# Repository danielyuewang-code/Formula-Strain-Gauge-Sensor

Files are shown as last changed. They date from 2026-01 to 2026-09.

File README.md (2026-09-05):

# Formula Strain Gauge Sensor
> PCB designs for measuring axial forces on suspension arms in Formula SAE racing applications

## Overview
This repository contains the Altium Designer PCB projects for strain gauge sensor systems designed to measure axial forces on suspension arms in formula racing vehicles. The project includes two design variants optimized for different size and performance requirements.

## Project Structure
### `/CIU` - Full-Featured MCU Board
The larger variant featuring a complete microcontroller solution for data acquisition and processing.
- **biggie.PrjPcb** - Main Altium project file
- **MCU.SchDoc** - Schematic design with MCU, signal conditioning, and power management

### `/smol` - Compact Sensor Board
The compact variant optimized for space-constrained installations.
- **smol.PrjPcb** - Main Altium project file
- **root.SchDoc** - Schematic design
- **smol.PcbDoc** - PCB layout

### `/docs`
Project documentation and design notes.

## Features
- Strain gauge signal conditioning and amplification
- Microcontroller-based data acquisition
- Axial force measurement capabilities
- Multiple size variants for different installation requirements
- Designed for harsh racing environments

## Hardware Requirements
- Altium Designer (for viewing/editing design files)
- Strain gauge sensors (specifications TBD)
- Power supply requirements (specifications TBD)

## Getting Started
1. Clone this repository
2. Open the desired project (.PrjPcb) in Altium Designer
3. Review the schematic and PCB layout files
4. Generate manufacturing outputs as needed

## Design Variants
- **Biggie** - Full-featured board with integrated MCU for standalone operation
- **Smol** - Amplifier board feeding signals

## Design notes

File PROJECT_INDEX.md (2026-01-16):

# Project Index - Formula Strain Gauge Sensor

## Project Overview
**Project Name:** Formula Strain Gauge Sensor  

---

## Repository Structure

```
Formula-Strain-Gauge-Sensor/
├── README.md                      # Project overview and getting started guide
├── PROJECT_INDEX.md               # This file - detailed project index
├── .gitignore                     # Git ignore rules
│
├── biggie/                        # Full-featured MCU variant
│   ├── biggie.PrjPcb             # Main Altium project file
│   ├── MCU.SchDoc                # Schematic - MCU, signal conditioning, power
│   └── __Previews/               # Altium preview files
│       └── MCU.SchDocPreview
│
├── smol/                          # Compact sensor variant
│   ├── smol.PrjPcb               # Main Altium project file
│   ├── root.SchDoc               # Schematic design
│   ├── smol.PcbDoc               # PCB layout
│   ├── __Previews/               # Altium preview files
│   │   └── root.SchDocPreview
│   └── History/                  # Altium version history
│
└── docs/                          # Documentation
    └── Design_Folder.md          # Design documentation
```

---

## Design Variants

### 1. Biggie (Full-Featured Board)
**Location:** `/biggie`  
**Description:** Complete microcontroller-based data acquisition system

**Key Files:**
- `biggie.PrjPcb` - Altium project container
- `MCU.SchDoc` - Main schematic with MCU and signal conditioning

---

### 2. Smol (Compact Board)
**Location:** `/smol`  
**Description:** Space-optimized sensor board for constrained installations

**Key Files:**
- `smol.PrjPcb` - Altium project container
- `root.SchDoc` - Schematic design
- `smol.PcbDoc` - PCB layout

---

## Quick Reference

### Opening Projects
1. Navigate to desired variant folder (`biggie/` or `smol/`)
2. Open the `.PrjPcb` file in Altium Designer
3. Access schematics and PCB files from the project panel

### Documentation
- Design decisions and specifications: `/docs/Design_Folder.md`
- General project info: `README.md`
- Project navigation: This file (`PROJECT_INDEX.md`)

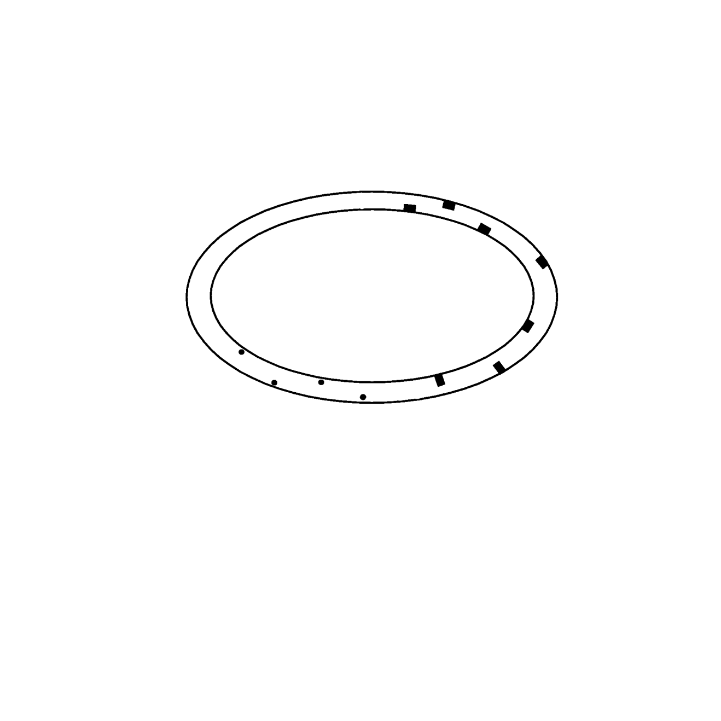
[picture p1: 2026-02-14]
custom_track_2.webp

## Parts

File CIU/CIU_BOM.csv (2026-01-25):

Comment | Description | Designator | Footprint | LibRef | Quantity
1u | CC0603KRX7R7BB105 | C1, C2, C3, C4, C5, C7 | CAPC1608X90N | CC0603KRX7R7BB105 | 6
10u | GRM188R61A106ME69D | C6, C16, C21, C26, C27, C28, C29, C30, C31, C32, C33 | GRM18x | GRM188R61A106ME69D | 11
8p | CGA3E2C0G1H080D080AA | C8, C9 | CAPC1608X90N | CGA3E2C0G1H080D080AA | 2
2u2 | CL10B225KP8NNNC | C10, C11, C23, C24 | CAPC1608X90N | CL10B225KP8NNNC | 4
470u | UWT1E471MNL1GS | C12, C14 | CAPAE1030X1080N | UWT1E471MNL1GS | 2
0.1u | CC0603KRX7R8BB104 | C13, C15, C25, C35 | CAPC1608X90N | CC0603KRX7R8BB104 | 4
22u | GRM219R61A226MEA0D | C17, C18, C19, C20 | CAPC2012X95N | GRM219R61A226MEA0D | 4
DNP | CL10B225KP8NNNC | C22_0, C22_1, C22_2, C22_3, C22_4, C22_5, C22_6, C22_7 | CAPC1608X90N | CL10B225KP8NNNC | 8
16V 26V | SMAJ16CA-13-F | D1 | DIONM5226X240N | SMAJ16CA-13-F | 1
TSSA3U45 | Schottky Diode | D2 | DIOM5126X250N | TSSA3U45 | 1
SML-D12P8WT86C | LED | D2 LED, LED1, LED2 | LEDM1620X150N | SML-D12P8WT86C | 3
DESD5V0U1BA-7 | TVS Diode (Bi-directional) | D3_0, D3_1, D3_2, D3_3, D3_4, D3_5, D3_6, D3_7 | SOD2513X120N | DESD5V0U1BA-7 | 8
0.22 V 1A | LSM115JE3_TR13 | D4, D5, D6 | DIOM5436X330N | LSM115JE3_TR13 | 3
3A | 0685T3000-01 | F1 | FUSC3216X83N | 0685T3000-01 | 1
1A | ERB-RE1R00V | F2, F3, F4, F5, F6, F7, F8, F9 | ERBRE0R50V | ERB-RE1R00V | 8
ferrite bead 0805 | FBMJ2125HS250NT | FB1 | BEADC2012X105N | FBMJ2125HS250NT | 1
BLM18KG121TN1D | Ferrite Bead | FB2 | BLM18EG101TH1D | BLM18KG121TN1D | 1
5V | TS2596CM550_RNG | IC1 | TS2596CM550RNG | TS2596CM550_RNG | 1
SI4214DDY-T1-GE3 | Integrated Circuit | IC2 | SOIC127P600X175-8N | SI4214DDY-T1-GE3 | 1
3.3V | LD1085D2M33R | IC3 | TO254P1542X460-3N | LD1085D2M33R | 1
INA214AIDCKR | Integrated Circuit | IC4 | SOT65P210X110-6N | INA214AIDCKR | 1
ATA6560-GAQW-N | Integrated Circuit | IC5 | SOIC127P600X175-8N | ATA6560-GAQW-N | 1
USB4105-GF-A | CONN RCPT USB2.0 TYPEC 5A | J1 | FP-USB4105-GF-A-MFG | CMP-245163-000001-1 | 1
6437288-1 | Connector | J2 | 6437288-1 | 6437288-1 | 1
61300511121 | Connector | J3 | HDRV5W64P0X254_1X5_1270X254X854P | 61300511121 | 1
47u | 104CDMCCDS-470MC | L1 | 104CDMCCDS470MC | 104CDMCCDS-470MC | 1
22 | RMCF0603JT22R0 | R1, R2 | RESC1608X55N | RMCF0603JT22R0 | 2
10k | RC0603FR0710KL | R3, R4, R7, R23 | RESC1608X55N | RC0603FR0710KL | 4
0 | RC0603JR-070RL | R5, R6 | RESC1608X55N | RC0603JR-070RL | 2
0.01 | CSS0603FT10L0 | R8 | CSS0603FT10L0 | CSS0603FT10L0 | 1
2.74M | CRCW06032M74FKEA | R9 | RESC1608X50N | CRCW06032M74FKEA | 1
510k | RC0603JR-07510KL | R10 | RESC1608X55N | RC0603JR-07510KL | 1
4.7k | RC0603FR-074K7L | R11, R22 | RESC1608X55N | RC0603FR-074K7L | 2
215k | ERJ-3EKF2153V | R12 | RESC1608X55N | ERJ-3EKF2153V | 1
84.5k | RC0603FR-0784K5L | R13 | RESC1608X55N | RC0603FR-0784K5L | 1
1.5k | RC0603FR-071K5L | R14 | RESC1608X55N | RC0603FR-071K5L | 1
56 | RC0805FR-0756RL | R15, R17 | RESC2012X60N | RC0805FR-0756RL | 2
140 | RC0805FR-07140RL | R16 | RESC2012X60N | RC0805FR-07140RL | 1
340 | RC0603FR-07340RL | R18_0, R18_1, R18_2, R18_3, R18_4, R18_5, R18_6, R18_7 | RESC1608X55N | RC0603FR-07340RL | 8
665 | RC0603FR-07665RL | R19_0, R19_1, R19_2, R19_3, R19_4, R19_5, R19_6, R19_7 | RESC1608X55N | RC0603FR-07665RL | 8
ERA-6AEB103V | Metal Film Chip Resistor, High Reliability Type, 0.125 W, +/- 0.1%, -55 to 155 degC, 0805 (2012 Metric), RoHS, Tape and Reel | R20, R21 | RESC2013X60X40LL20T25_A | CMP-2001-00582-2 | 2
60.4 | ERJ-PA3F60R4V | R24 | ERJP03_PA3_(0603) | ERJ-PA3F60R4V | 1
SDA01H1SBD | Switch | S1 | SDA01H1SBD | SDA01H1SBD | 1
PRTR5V0U2X,215 | Ultra Low Capacitance Double Rail-to-Rail ESD Protection Diode, 5.5 V, 1 pF, -40 to 85 degC, 4-Pin SOT143B, RoHS, Tape and Reel | TVS1 | NXP-SOT143B-4_V | CMP-2000-05285-1 | 1
STM32F405RGT7 | ARM Cortex-M4 32-bit MCU+FPU, 210 DMIPS, 1024 kB Flash, 192 kB Internal RAM, 51 I/Os, 64-pin LQFP, -40 to 105 degC, Tray | U1 | STM-LQFP64_N | CMP-0243-00093-2 | 1
LTC4365ITS8#TRMPBF | UV, OV and Reverse Supply Protection Controller, 2.5 to 34 V Vin, 8-pin SOT23 (TS8-8), -40 to 85 degC, Pb-Free, Mini Tape and Reel | U2 | LT-TS8-8-TSOT-23_V | CMP-0474-00861-1 | 1
8 MHz | AA-8.000MALV-T | X1 | ABRA-ABM3-2_V | CMP-2000-05033-1 | 1

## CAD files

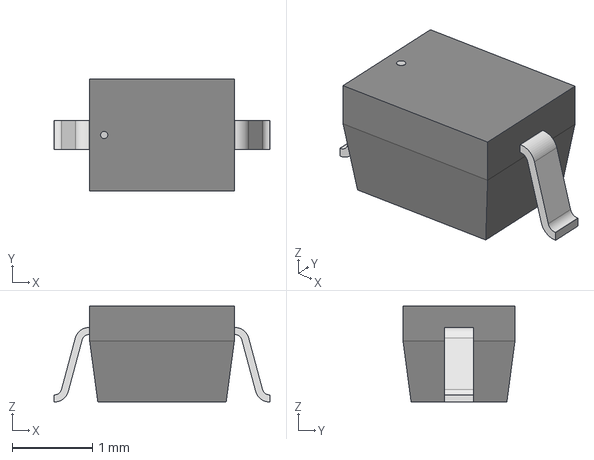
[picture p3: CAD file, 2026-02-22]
CIU/Datasheets/DESD5V0U1BA_7/Altium/DESD5V0U1BA-7/SOD323-L_DIO.step
2.69 x 1.40 x 1.20 mm

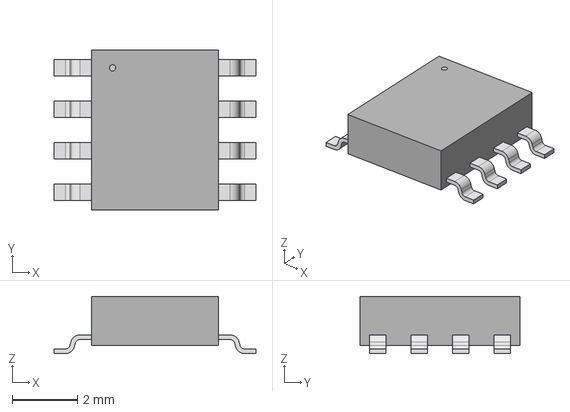
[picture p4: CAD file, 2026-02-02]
CIU/Parts/CAN/SOIC8_4P9X3P9MC_MCH.step
6.20 x 4.90 x 1.75 mm

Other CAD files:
CIU/Datasheets/DESD5V0U1BA_7/SOD323-L_DIO.step

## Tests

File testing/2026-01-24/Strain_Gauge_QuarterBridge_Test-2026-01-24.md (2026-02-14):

# Strain Gauge Quarter-Bridge Test

Daniel Wang  
2026-01-24  

---

## 1. Objective
Verify quarter-bridge strain gauge readings, op-amp amplification, and ESP32 ADC response to applied strain.

---

## 2. Test Setup

### 2.1 Hardware
- Strain Gauge: 350 Ω
- Bridge Configuration: Quarter-bridge
- Bridge Resistors: 3 × 100 Ω, 1 × 51 Ω (didn't have 350 Ω resistors on hand)
- Excitation Voltage: 3.3 V
- Op-Amp: MCP6002 (single op-amp, non-inverting configuration)
- Gain: ~100 (100 kΩ / 1 kΩ)
- MCU: ESP32-WROOM-32D
- ADC Pin: GPIO32

**See Breadboard Setup:**
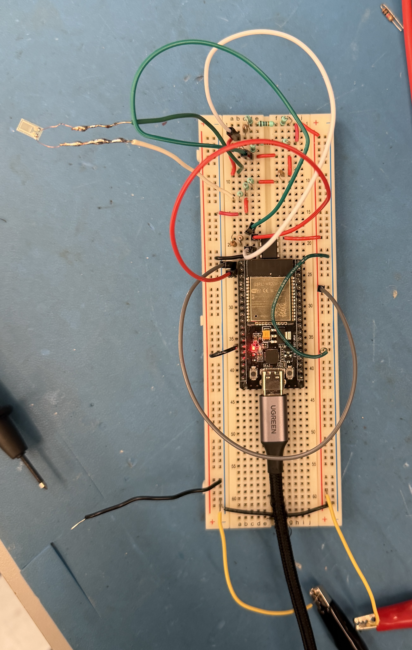
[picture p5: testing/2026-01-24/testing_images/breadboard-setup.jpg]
Breadboard setup


### 2.2 Signal Chain
```text
Strain Gauge (350 Ω)
→ Wheatstone Quarter Bridge (~351 Ω)
→ Op-Amp (Gain ≈ 100)
→ ESP32 ADC (GPIO32)
→ Serial Monitor
```

---

## 3. Testing

### 3.1 Testing Each Layer

#### Wheatstone Quarter Bridge
- Measured bridge output with multimeter
    - Output (no strain): fluctuating ~0.1 mV
    - When manually bending strain gauge with hands: ~1 mV

#### Op-Amp
- Output (no strain): ~2.4 V
- Amplified output when manually bending with hands: ~100 mV (expected 100x gain)

Note: A mid-supply bias (1.65 V) was not implemented in this test; the op-amp reference was tied to ground. As a result, the DC operating point was undefined, and an output offset of ~2.4 V was observed. Input impedance mismatch between the bridge and op-amp inputs likely contributed to this offset. Future designs should include buffer op-amps prior to the gain stage.

### 3.2 ESP32 Reading
- Op-amp connected to ADC pin GPIO32
- Serial moniter on Arduino IDE

#### MCU Sanity Check
- LED blink test and ADC read test
**Note for our ESP, there was no auto-reboot, BOOT button must be held down during upload.

#### ADC Test Code
Serial moniter baud rate: 115200
```cpp
void setup() {
  Serial.begin(115200);
}

void loop() {
  int raw = analogRead(36);
  Serial.println(raw);
  delay(500);
}
```

#### Voltage Conversion Code
```cpp
void setup() {
  Serial.begin(115200);
}

void loop() {
  int raw = analogRead(36);
  float voltage = (raw / 4095.0) * 3.3;
  Serial.print("ADC: ");
  Serial.print(raw);
  Serial.print(" Voltage: ");
  Serial.println(voltage, 3);
  delay(500);
}
```
From bending the strain gauge, max volatage readings from 3.3 V down to 0.4 V.

--- 

## 4. Next Steps
- waterjetted steel test piece (200x20x1.5 mm) to hang weights from and get proper calibration curve on serial moniter
- add the two op amps to balance current

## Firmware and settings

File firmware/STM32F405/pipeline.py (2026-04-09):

"""
pipeline.py

Strain Gauge Data Processing Pipeline
Formula Racing SAE — UBC

Reads raw ADC counts from CSV (logged by AIM data logger),
processes through a modular pipeline:

1. CANParser      — reads CSV, extracts raw ADC counts per channel
2. SensorCalibrator — converts ADC counts → voltage → force (Newtons)
3. DataFilter      — applies moving average filter to smooth noise
4. DataVisualizer  — plots force vs time (in visualizer.py)

Each class has one responsibility. Easy to test, easy to modify.
"""

import numpy as np
import csv

# ─────────────────────────────────────────────────────────
# CONSTANTS
# ─────────────────────────────────────────────────────────

ADC_RESOLUTION   = 4096    # 12-bit ADC: 0 to 4095 counts
VREF             = 3.3     # STM32 reference voltage (volts)
OFFSET_VOLTAGE   = 1.65    # Amplifier output at zero load (midpoint of 3.3V)
SENSITIVITY      = 500.0   # Newtons per volt — determined during calibration
FILTER_WINDOW    = 10      # Moving average window size (samples)
NUM_CHANNELS     = 4       # FL, FR, RL, RR

CHANNEL_NAMES = ["Front Left", "Front Right", "Rear Left", "Rear Right"]


# ─────────────────────────────────────────────────────────
# CLASS 1 — CAN PARSER
# Reads CSV exported from AIM data logger
# Extracts timestamps and raw ADC counts for each channel
# ─────────────────────────────────────────────────────────

class CANParser:
    """
    Reads CSV file exported from AIM data logger.

    The AIM logger records CAN messages and exports them as CSV.
    Each row is one CAN message (one 100Hz sample).
    Columns: timestamp, ch0_high, ch0_low, ch1_high, ch1_low, ...

    Reassembles high/low byte pairs back into uint16 ADC counts.
    """

    def __init__(self, filepath):
        """
        Parameters
        ----------
        filepath : str
            Path to CSV file exported from AIM logger
        """
        self.filepath   = filepath
        self.timestamps = None   # numpy array of timestamps (seconds)
        self.raw_adc    = None   # numpy array shape (num_samples, NUM_CHANNELS)

    def parse(self):
        """
        Read CSV and reconstruct ADC values from high/low byte pairs.

        CSV format expected:
            timestamp, ch0_H, ch0_L, ch1_H, ch1_L, ch2_H, ch2_L, ch3_H, ch3_L

        Returns
        -------
        self : CANParser
            Returns self so calls can be chained
        """
        timestamps = []
        raw_adc    = []

        with open(self.filepath, 'r') as f:
            reader = csv.reader(f)
            next(reader)  # skip header row

            for row in reader:
                timestamp = float(row[0])

                # Reassemble each channel from high byte and low byte
                # CAN packed: high byte first, low byte second
                # Reverse: (high << 8) | low = original uint16 ADC count
                channels = []
                for ch in range(NUM_CHANNELS):
                    high_byte = int(row[1 + ch * 2])
                    low_byte  = int(row[2 + ch * 2])
                    adc_count = (high_byte << 8) | low_byte
                    channels.append(adc_count)

                timestamps.append(timestamp)
                raw_adc.append(channels)

        # Convert to numpy arrays for fast vectorized operations
        self.timestamps = np.array(timestamps)             # shape: (N,)
        self.raw_adc    = np.array(raw_adc, dtype=float)  # shape: (N, 4)

        print(f"Parsed {len(self.timestamps)} samples from {self.filepath}")
        return self


# ─────────────────────────────────────────────────────────
# CLASS 2 — SENSOR CALIBRATOR
# Converts raw ADC counts → voltage → force (Newtons)
#
# Step 1: ADC count → voltage
#         voltage = (adc_count / ADC_RESOLUTION) × VREF
#
# Step 2: Remove zero-load offset
#         delta_voltage = voltage - OFFSET_VOLTAGE
#         (amplifier outputs 1.65V midpoint at zero load)
#
# Step 3: Voltage → Force
#         force = delta_voltage × SENSITIVITY
#         (sensitivity determined by applying known weights during calibration)
# ─────────────────────────────────────────────────────────

class SensorCalibrator:
    """
    Converts raw ADC counts to force in Newtons.

    Uses a linear calibration model:
        force = (adc_voltage - offset) × sensitivity

    Calibration constants determined experimentally:
    known weights were applied to suspension and ADC output recorded.
    Linear regression on (weight, voltage) pairs gave sensitivity and offset.
    """

    def __init__(self, sensitivity=SENSITIVITY, offset_voltage=OFFSET_VOLTAGE,
                 adc_resolution=ADC_RESOLUTION, vref=VREF):
        """
        Parameters
        ----------
        sensitivity    : float — Newtons per volt
        offset_voltage : float — amplifier output at zero load (volts)
        adc_resolution : int   — ADC full scale count (4096 for 12-bit)
        vref           : float — reference voltage (volts)
        """
        self.sensitivity    = sensitivity
        self.offset_voltage = offset_voltage
        self.adc_resolution = adc_resolution
        self.vref           = vref

    def counts_to_voltage(self, adc_counts):
        """
        Convert ADC counts to voltage.

        Parameters
        ----------
        adc_counts : np.ndarray — raw ADC values (0 to 4095)

        Returns
        -------
        np.ndarray — voltage in volts
        """
        return (adc_counts / self.adc_resolution) * self.vref

    def voltage_to_force(self, voltage):
        """
        Convert voltage to force in Newtons.

        Removes zero-load offset then applies sensitivity scaling.

        Parameters
        ----------
        voltage : np.ndarray — voltage in volts

        Returns
        -------
        np.ndarray — force in Newtons
        """
        delta_voltage = voltage - self.offset_voltage
        return delta_voltage * self.sensitivity

    def calibrate(self, raw_adc):
        """
        Full calibration: ADC counts → voltage → force.

        Parameters
        ----------
        raw_adc : np.ndarray shape (N, 4) — raw ADC counts

        Returns
        -------
        np.ndarray shape (N, 4) — force in Newtons for each channel
        """
        voltage = self.counts_to_voltage(raw_adc)
        force   = self.voltage_to_force(voltage)
        return force


# ─────────────────────────────────────────────────────────
# CLASS 3 — DATA FILTER
# Moving average filter — smooths high frequency noise
#
# For each sample, replaces the value with the average
# of the surrounding window of samples.
#
# This is a digital low pass filter — slow suspension changes
# pass through, fast electrical noise gets averaged out.
# ─────────────────────────────────────────────────────────

class DataFilter:
    """
    Applies moving average filter to force data.

    Moving average is a simple digital low pass filter.
    Replaces each sample with the mean of the surrounding window.

    Uses numpy.convolve with a uniform kernel — efficient vectorized
    operation instead of a Python loop.
    """

    def __init__(self, window_size=FILTER_WINDOW):
        """
        Parameters
        ----------
        window_size : int — number of samples to average over
                           larger = more smoothing, more lag
        """
        self.window_size = window_size

    def apply(self, force_data):
        """
        Apply moving average filter to all channels.

        Parameters
        ----------
        force_data : np.ndarray shape (N, 4) — force in Newtons

        Returns
        -------
        np.ndarray shape (N, 4) — filtered force data
        """
        num_samples, num_channels = force_data.shape
        filtered = np.zeros_like(force_data)

        # Uniform kernel — every sample in window gets equal weight
        # Example window_size=5: kernel = [0.2, 0.2, 0.2, 0.2, 0.2]
        kernel = np.ones(self.window_size) / self.window_size

        for ch in range(num_channels):
            # np.convolve slides the kernel across the signal
            # 'same' mode: output is same length as input
            filtered[:, ch] = np.convolve(force_data[:, ch], kernel, mode='same')

        return filtered


# ─────────────────────────────────────────────────────────
# CLASS 4 — DATA PROCESSOR
# Orchestrates the full pipeline:
# parse → calibrate → filter → return processed data
# ─────────────────────────────────────────────────────────

class DataProcessor:
    """
    Orchestrates the full processing pipeline.

    Combines CANParser, SensorCalibrator, and DataFilter
    into a single run() call.

    Stores results as attributes for downstream use
    (visualization, export, analysis).
    """

    def __init__(self, filepath, window_size=FILTER_WINDOW):
        """
        Parameters
        ----------
        filepath    : str — path to AIM CSV file
        window_size : int — moving average window size
        """
        self.parser     = CANParser(filepath)
        self.calibrator = SensorCalibrator()
        self.filter     = DataFilter(window_size)

        # Results stored after run()
        self.timestamps     = None   # (N,) timestamps in seconds
        self.raw_adc        = None   # (N, 4) raw ADC counts
        self.force_raw      = None   # (N, 4) calibrated but unfiltered force
        self.force_filtered = None   # (N, 4) calibrated and filtered force

    def run(self):
        """
        Execute full pipeline: parse → calibrate → filter.

        Returns
        -------
        self : DataProcessor
            Returns self for method chaining
        """
        # Step 1: Parse CSV
        self.parser.parse()
        self.timestamps = self.parser.timestamps
        self.raw_adc    = self.parser.raw_adc

        # Step 2: Calibrate — ADC counts to force
        self.force_raw = self.calibrator.calibrate(self.raw_adc)

        # Step 3: Filter — smooth noise
        self.force_filtered = self.filter.apply(self.force_raw)

        print(f"Pipeline complete — {len(self.timestamps)} samples processed")
        return self

    def summary(self):
        """
        Print summary statistics for each channel.
        """
        if self.force_filtered is None:
            print("Run pipeline first with .run()")
            return

        print("\n── Suspension Load Summary ──")
        for ch, name in enumerate(CHANNEL_NAMES):
            data = self.force_filtered[:, ch]
            print(f"{name:12s} | "
                  f"Mean: {np.mean(data):8.1f} N | "
                  f"Max:  {np.max(data):8.1f} N | "
                  f"Min:  {np.min(data):8.1f} N | "
                  f"Std:  {np.std(data):6.1f} N")


# ─────────────────────────────────────────────────────────
# ENTRY POINT
# ─────────────────────────────────────────────────────────

if __name__ == "__main__":
    # Run full pipeline on a data file
    processor = DataProcessor("data/run_001.csv", window_size=10)
    processor.run()
    processor.summary()

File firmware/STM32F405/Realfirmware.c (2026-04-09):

/**
 * strain_gauge_firmware.c
 * 
 * STM32 Firmware — Strain Gauge Data Acquisition System
 * Formula Racing SAE — UBC
 * 
 * What this firmware does:
 * 1. ADC continuously reads raw voltage from strain gauge amplifier via DMA
 * 2. DMA moves ADC readings into memory automatically (no CPU involvement)
 * 3. Timer fires at 100Hz
 * 4. CAN transmits raw ADC values to AIM data logger at 100Hz
 * 
 * All calibration and filtering done in post-processing (Python pipeline)
 */

#include "stm32f4xx_hal.h"
#include <stdint.h>

/* ─────────────────────────────────────────────────────────
   HARDWARE HANDLES
   Structs HAL uses to track the state of each peripheral.
   Pass these into every HAL function call.
   ───────────────────────────────────────────────────────── */
ADC_HandleTypeDef hadc1;
DMA_HandleTypeDef hdma_adc1;
CAN_HandleTypeDef hcan1;
TIM_HandleTypeDef htim2;

/* ─────────────────────────────────────────────────────────
   CONSTANTS
   ───────────────────────────────────────────────────────── */
#define NUM_CHANNELS  4    // FL, FR, RL, RR strain gauges

/* ─────────────────────────────────────────────────────────
   BUFFERS
   ───────────────────────────────────────────────────────── */

/**
 * DMA buffer — ADC results land here automatically in hardware
 *
 * volatile: this memory is written by DMA hardware outside of
 * normal code flow, so compiler must always read it fresh
 *
 * Layout: [CH0, CH1, CH2, CH3] — one uint16 per channel
 * Each value is a 12-bit ADC count (0 to 4095)
 */
volatile uint16_t adc_dma_buffer[NUM_CHANNELS];

/**
 * 100Hz transmit flag — set by timer ISR, cleared by main loop
 */
volatile uint8_t can_transmit_flag = 0;

/* ─────────────────────────────────────────────────────────
   FUNCTION DECLARATIONS
   ───────────────────────────────────────────────────────── */
void SystemClock_Config(void);
void MX_ADC1_Init(void);
void MX_DMA_Init(void);
void MX_CAN1_Init(void);
void MX_TIM2_Init(void);
void transmit_can_message(void);
void Error_Handler(void);

/* ─────────────────────────────────────────────────────────
   MAIN
   ───────────────────────────────────────────────────────── */
int main(void)
{
    HAL_Init();
    SystemClock_Config();

    /* DMA must init before ADC */
    MX_DMA_Init();
    MX_ADC1_Init();
    MX_CAN1_Init();
    MX_TIM2_Init();

    /**
     * Start ADC in DMA circular mode
     * ADC scans all 4 channels continuously
     * DMA writes each result into adc_dma_buffer automatically
     * CPU does nothing — hardware handles it
     */
    if (HAL_ADC_Start_DMA(&hadc1, (uint32_t*)adc_dma_buffer, NUM_CHANNELS) != HAL_OK)
    {
        Error_Handler();
    }

    /* Start CAN peripheral */
    if (HAL_CAN_Start(&hcan1) != HAL_OK)
    {
        Error_Handler();
    }

    /**
     * Start timer interrupt at 100Hz
     * Every 10ms the timer ISR sets can_transmit_flag = 1
     */
    if (HAL_TIM_Base_Start_IT(&htim2) != HAL_OK)
    {
        Error_Handler();
    }

    /* ── MAIN LOOP ── */
    while (1)
    {
        /**
         * Check if 100Hz timer has fired
         * If yes — transmit whatever is currently in adc_dma_buffer
         * DMA is continuously keeping that buffer up to date
         */
        if (can_transmit_flag)
        {
            can_transmit_flag = 0;
            transmit_can_message();
        }
    }
}

/* ─────────────────────────────────────────────────────────
   CAN TRANSMISSION
   
   Packs raw ADC values into CAN message and sends to AIM logger.
   
   4 channels x 2 bytes = 8 bytes — fits exactly in one CAN frame.
   
   AIM logger receives raw ADC counts.
   Python pipeline later converts counts to voltage to force.
   ───────────────────────────────────────────────────────── */
void transmit_can_message(void)
{
    CAN_TxHeaderTypeDef TxHeader;
    uint8_t TxData[8];
    uint32_t TxMailbox;

    TxHeader.StdId = 0x123;        // Custom ID — AIM logger listens for this
    TxHeader.IDE   = CAN_ID_STD;   // Standard 11-bit ID
    TxHeader.RTR   = CAN_RTR_DATA; // Data frame
    TxHeader.DLC   = 8;            // 8 bytes of payload

    /**
     * Pack 4 raw ADC values (uint16) into 8 bytes
     * Each value split into high byte and low byte
     *
     * Example: ADC reads 2048 (0x0800)
     * TxData[0] = 0x08  (high byte)
     * TxData[1] = 0x00  (low byte)
     *
     * AIM reassembles: (0x08 << 8) | 0x00 = 2048
     * Python then converts 2048 counts to voltage to force
     */
    for (uint8_t ch = 0; ch < NUM_CHANNELS; ch++)
    {
        TxData[ch * 2]     = (uint8_t)((adc_dma_buffer[ch] >> 8) & 0xFF); // high byte
        TxData[ch * 2 + 1] = (uint8_t)(adc_dma_buffer[ch] & 0xFF);        // low byte
    }

    if (HAL_CAN_AddTxMessage(&hcan1, &TxHeader, TxData, &TxMailbox) != HAL_OK)
    {
        Error_Handler();
    }
}

/* ─────────────────────────────────────────────────────────
   TIMER ISR CALLBACK
   
   Called by HAL every time Timer 2 fires (every 10ms = 100Hz)
   Just sets the flag — transmission happens in main loop
   Keeps ISR as short as possible
   ───────────────────────────────────────────────────────── */
void HAL_TIM_PeriodElapsedCallback(TIM_HandleTypeDef *htim)
{
    if (htim->Instance == TIM2)
    {
        can_transmit_flag = 1;
    }
}

/* ─────────────────────────────────────────────────────────
   ADC INIT
   4 channels, 12-bit, continuous scan, DMA enabled
   ───────────────────────────────────────────────────────── */
void MX_ADC1_Init(void)
{
    ADC_ChannelConfTypeDef sConfig = {0};

    hadc1.Instance                   = ADC1;
    hadc1.Init.ClockPrescaler        = ADC_CLOCK_SYNC_PCLK_DIV4;
    hadc1.Init.Resolution            = ADC_RESOLUTION_12B;      // 0 to 4095
    hadc1.Init.ScanConvMode          = ENABLE;                  // Scan all 4 channels
    hadc1.Init.ContinuousConvMode    = ENABLE;                  // Keep scanning forever
    hadc1.Init.DiscontinuousConvMode = DISABLE;
    hadc1.Init.ExternalTrigConv      = ADC_SOFTWARE_START;
    hadc1.Init.DataAlign             = ADC_DATAALIGN_RIGHT;
    hadc1.Init.NbrOfConversion       = NUM_CHANNELS;
    hadc1.Init.DMAContinuousRequests = ENABLE;                  // DMA keeps running

    if (HAL_ADC_Init(&hadc1) != HAL_OK) Error_Handler();

    uint32_t channels[NUM_CHANNELS] = {
        ADC_CHANNEL_0,  // Front Left
        ADC_CHANNEL_1,  // Front Right
        ADC_CHANNEL_2,  // Rear Left
        ADC_CHANNEL_3   // Rear Right
    };

    for (uint8_t i = 0; i < NUM_CHANNELS; i++)
    {
        sConfig.Channel      = channels[i];
        sConfig.Rank         = i + 1;
        sConfig.SamplingTime = ADC_SAMPLETIME_480CYCLES;
        if (HAL_ADC_ConfigChannel(&hadc1, &sConfig) != HAL_OK) Error_Handler();
    }
}
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

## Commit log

2026-01-12 added schemtic and docs folder
    [MCU.SchDoc]
2026-01-15 added smol board to repo
    [root.SchDoc, smol.PcbDoc, smol.PrjPcb]
2026-01-15 added sum shit
    [MCU.SchDoc, biggie.PrjPcb]
2026-01-15 tentative layout done for smol
    [root.SchDoc, smol.PcbDoc]
2026-01-16 added previous ciu
    [CIU.PrjPcb]
2026-01-17 added shit
    [biggie.PrjPcb]
2026-01-17 big penis
    [CAN.SchDoc, STlink.SchDoc]
2026-01-17 Update PCB layout
    [smol.PcbDoc]
2026-01-17 Update PCB
    [smol.PcbDoc]
2026-01-22 completely redid placement and routing im so sorry nathan
    [smol.PcbDoc]
2026-01-22 small board done
    [smol.PcbDoc]
2026-01-22 added silkscreen back
    [smol.PcbDoc]
2026-01-25 finished small board, ready for verif and manu
    [root.SchDoc, smol.PcbDoc, smol.PrjPcb]
2026-01-31 power parts
    [Supply.SchDoc]
2026-02-01 power DONE
    [MCU.SchDoc, Supply.SchDoc]
2026-02-01 deleted usb and need to add pad later
    [CIU.PRT, Supply.SchDoc]
2026-02-01 properly added now
    [CIU.PrjPcb]
2026-02-01 um work pls
    [CIU.PcbDoc, Input_Conditioner.SchDoc, Root.SchDoc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]
2026-02-01 deleting unneccesary files
    [CIU.PrjPcb, Current_Sense.SchDoc, USB.SchDoc]
2026-02-01 pads added
    [Can_Interface.SchDoc, Conditioner_Array.SchDoc, Root.SchDoc]
2026-02-01 corrected pins for STM32
    [MCU.SchDoc, STlink.SchDoc]
2026-02-01 all files saved
    [Root.SchDoc]
2026-02-01 removed current sensor
    [Root.SchDoc]
2026-02-01 changed input location
    [MCU.SchDoc, Root.SchDoc]
2026-02-01 fixed 1 warning
    [Supply.SchDoc]
2026-02-02 some changes
    [ATA6560-GAQW-N.PcbLib, ATA6560-GAQW-N.SchLib, CIU.PcbDoc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]
2026-02-04 finished smol
    [root.SchDoc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]
2026-02-06 small wang
    [MCU.SchDoc, MCUreal.SchDoc]
2026-02-07 bigg dick
    [MCUreal.SchDoc]
2026-02-14 fixing some errors
    [MCU.SchDoc]
2026-02-14 getting rid of errors
    [MCU.SchDoc]
2026-02-15 ooga booga
    [CIU.PrjPcb, Conditioner_Array.SchDoc, Ferrite_bead.PcbLib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]
2026-02-15 huge penus
    [CIU.PrjPcb, Can_Interface.SchDoc, Connectors.SchDoc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]
2026-02-15 oooga booga googa
    [Can_Interface.SchDoc, Input_Conditioner.SchDoc, MCU.SchDoc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]
2026-02-15 ooga booga googa
    [MCU.SchDoc]
2026-02-15 added differential pair for routing
    [Can_Interface.SchDoc, OUR_CIU.PcbDoc]
2026-02-15 adding differential on updated
    [Can_Interface.SchDoc, OUR_CIU.PcbDoc]
2026-02-15 organized components
    [MCU.SchDoc, OUR_CIU.PcbDoc, Supply.SchDoc]
2026-02-21 booga googgs
    [Connectors.SchDoc, Supply.SchDoc]
2026-02-21 reorganized pieces
    [OUR_CIU.PcbDoc]
2026-02-22 organized pt2
    [OUR_CIU.PcbDoc]
2026-02-23 power lines somewhat fixed :)
    [OUR_CIU.PcbDoc]
2026-02-27 new stuff
    [Input_Conditioner.SchDoc, MCU.SchDoc, STlink.SchDoc]
2026-02-28 its 2:52am
    [OUR_CIU.PcbDoc]
2026-02-28 some changes to space it out
    [OUR_CIU.PcbDoc]
2026-02-28 more changes
    [OUR_CIU.PcbDoc]
2026-02-28 added lines
    [OUR_CIU.PcbDoc]
2026-02-28 reduced errors 369
    [CIU.PrjPcb, OUR_CIU.PcbDoc]
2026-02-28 reduced errors 363
    [OUR_CIU.PcbDoc]
2026-02-28 reduced errors 314
    [OUR_CIU.PcbDoc]
2026-02-28 reduced text sizde
    [OUR_CIU.PcbDoc]
2026-02-28 reduced errors 150
    [OUR_CIU.PcbDoc]
2026-03-01 reduced errors 72
    [OUR_CIU.PcbDoc]
2026-03-01 reduced errors 7
    [OUR_CIU.PcbDoc]
2026-03-01 reduced errors 46
    [OUR_CIU.PcbDoc]
2026-03-01 RESTORE POINT 36 ERRORS !!
    [Can_Interface.SchDoc, MCU.SchDoc, OUR_CIU.PcbDoc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]
2026-03-05 routed pcb mightve fucked it up
    [OUR_CIU.PcbDoc]
2026-03-05 last thing
    [OUR_CIU.PcbDoc]
2026-03-06 pour me a polygon
    [OUR_CIU.PcbDoc]
2026-03-07 cleaned up pcb
    [OUR_CIU.PcbDoc]
2026-03-07 point pt2
    [OUR_CIU.PcbDoc]
2026-03-07 reset point
    [OUR_CIU.PcbDoc]
2026-03-08 not done need fixing, gnd vias, decoupling, 3.3v
    [OUR_CIU.PcbDoc]
2026-03-14 top gnd added
    [OUR_CIU.PcbDoc]
2026-03-14 updated BOM
2026-03-14 good restore point
    [OUR_CIU.PcbDoc]
2026-03-14 0 errors now
    [OUR_CIU.PcbDoc]
2026-03-14 moved around
    [OUR_CIU.PcbDoc]
2026-03-15 0 error, via stitching, reshaped
    [OUR_CIU.PcbDoc]
2026-03-17 vias size adjusted to 18mil
    [OUR_CIU.PcbDoc]
2026-03-21 removed dead copper & added stitching!
    [OUR_CIU.PcbDoc]
2026-03-21 1 silk error :)
    [OUR_CIU.PcbDoc]
2026-03-22 final touches
    [OUR_CIU.PcbDoc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]
2026-03-22 keep out
    [OUR_CIU.PcbDoc]
2026-03-22 almost done???
    [OUR_CIU.PcbDoc]
2026-03-23 added border shape
    [OUR_CIU.PcbDoc]
2026-03-23 added NRST connection
    [CIU.PRT, OUR_CIU.PcbDoc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]
